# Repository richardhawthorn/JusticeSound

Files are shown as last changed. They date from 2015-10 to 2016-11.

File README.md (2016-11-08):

### Description

Justice Cross

### Features

- 28 LED display
- Charlieplex LED control
- ATTINY44 processor
- 3V operation @ 1Mhz or 8Mhz
- 1x button
- ICSP port
- Hole for necklace chain

### License

This work is licensed under a Creative Commons Attribution-ShareAlike 4.0 International License.

<br />
Designed by <a xmlns:cc="http://creativecommons.org/ns#" href="http://www.richardhawthorn.com" property="cc:attributionName" rel="cc:attributionURL" target="_blank">Richard Hawthorn</a><br />
<a rel="license" href="http://creativecommons.org/licenses/by-sa/4.0/" target="_blank">View License</a>

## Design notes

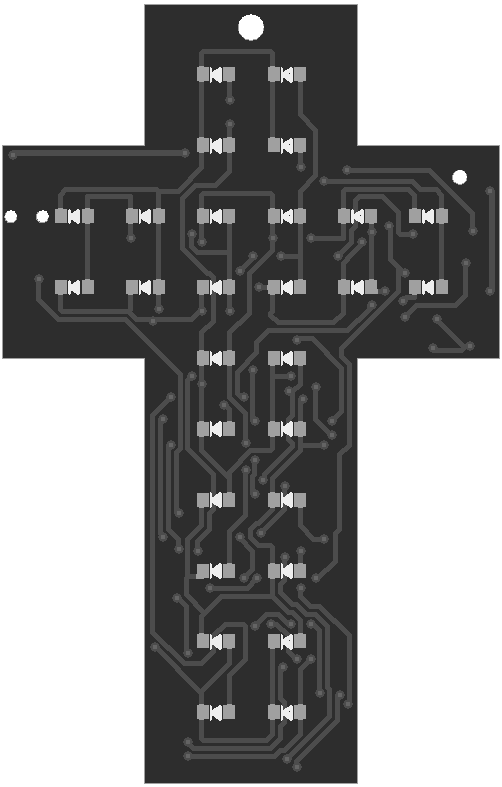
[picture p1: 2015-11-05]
images/pcb_front.png

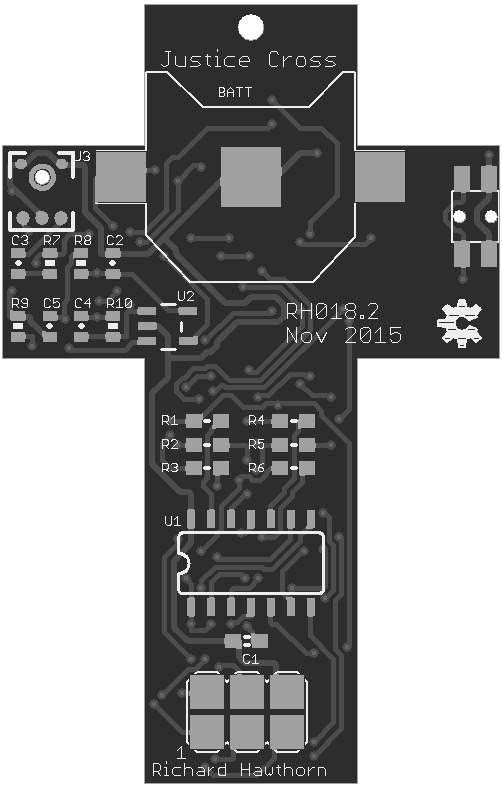
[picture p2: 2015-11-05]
images/pcb_back.png

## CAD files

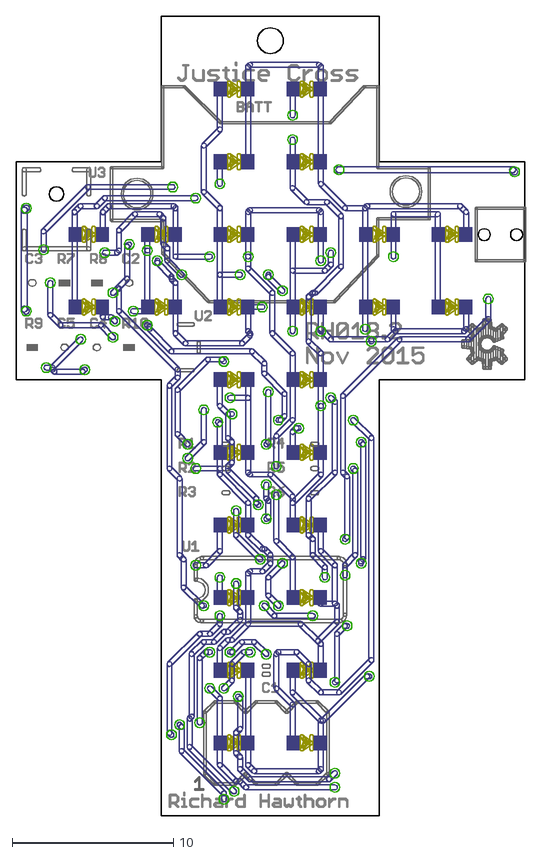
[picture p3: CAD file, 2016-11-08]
enclosure/RH018.2.dxf
31.6 x 49.5

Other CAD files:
enclosure/Enclosure.dxf

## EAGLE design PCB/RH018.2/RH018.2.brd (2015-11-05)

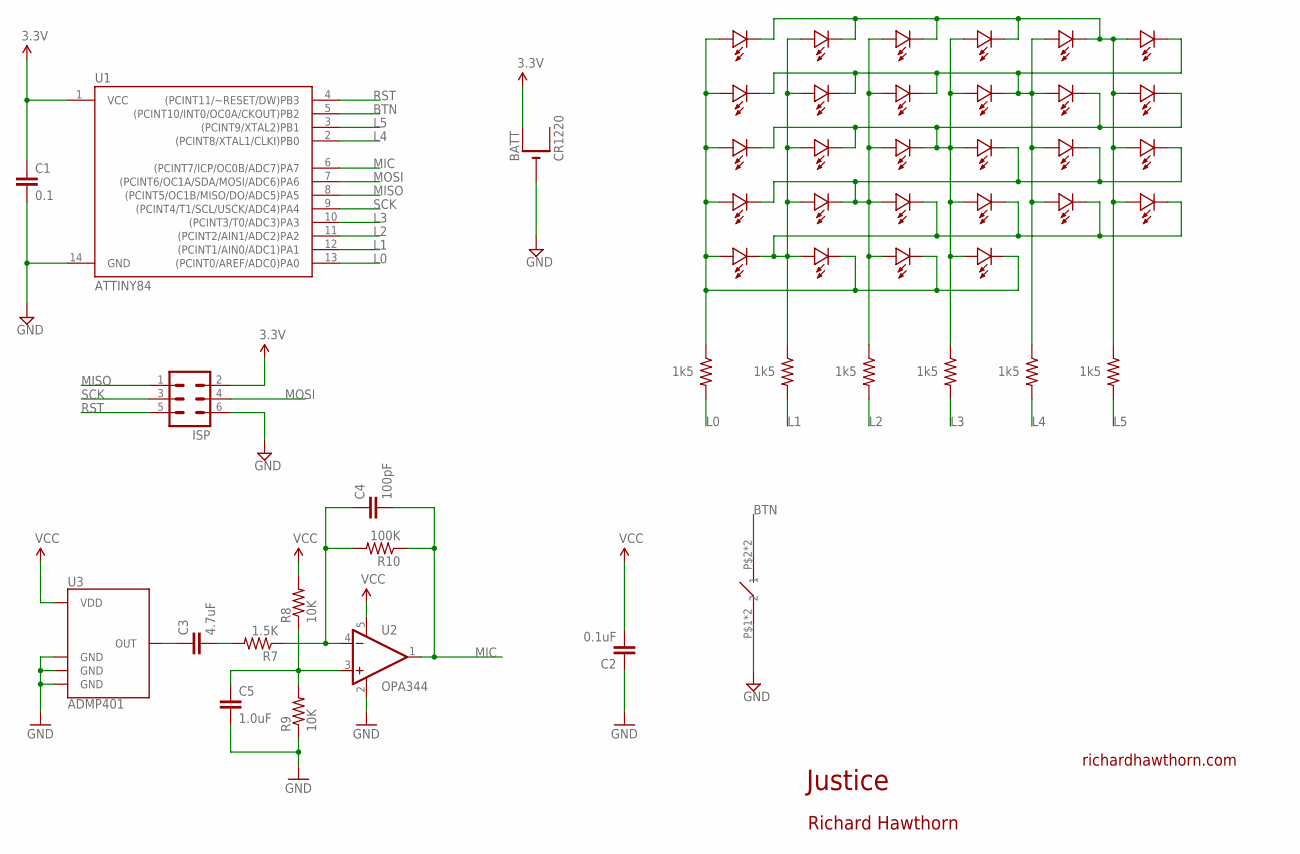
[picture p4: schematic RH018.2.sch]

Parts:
BATT: CR1220; CR1220-SMD
BTN1: TURTLE-3PIN
C1: 0.1; 0603-CAP
C2: 0.1uF; 0402-CAP
C3: 4.7uF; 0402-CAP
C4: 100pF; 0402-CAP
C5: 1.0uF; 0402-CAP
ISP: MA03-2
LED1, LED2, LED3, LED4, LED5, LED6, LED7, LED8, LED9, LED10, LED11, LED12, LED13, LED14, LED15, LED16, LED17, LED18, LED19, LED20, LED21, LED22, LED23, LED24, LED25, LED26, LED27, LED28: LED0603; 0603-LED
R1, R2, R3, R4, R5, R6: 1k5; 0603-RES
R7: 1.5K; 0402-RES
R8, R9: 10K; 0402-RES
R10: 100K; 0402-RES
U1: ATTINY84; SO14
U2: OPA344; SOT23-5
U3: ADMP401

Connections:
BTN: BTN1.P$2 (2), BTN1.P$4 (2), U1.5 ((PCINT10/INT0/OC0A/CKOUT)PB2)
C7N$1: C3.1, U3.1 (OUT)
GND: BATT.-, BTN1.P$1 (1), BTN1.P$3 (1), C1.2, C2.1, C5.2, ISP.6, R9.1, U1.14 (GND), U2.2 (V-), U3.2 (GND), U3.4 (GND), U3.6 (GND)
L0: R1.2, U1.13 ((PCINT0/AREF/ADC0)PA0)
L1: R2.2, U1.12 ((PCINT1/AIN0/ADC1)PA1)
L2: R3.2, U1.11 ((PCINT2/AIN1/ADC2)PA2)
L3: R4.2, U1.10 ((PCINT3/T0/ADC3)PA3)
L4: R5.2, U1.2 ((PCINT8/XTAL1/CLKI)PB0)
L5: R6.2, U1.3 ((PCINT9/XTAL2)PB1)
MIC: C4.2, R10.1, U1.6 ((PCINT7/ICP/OC0B/ADC7)PA7), U2.1 (OUT)
MISO: ISP.1, U1.8 ((PCINT5/OC1B/MISO/DO/ADC5)PA5)
MOSI: ISP.4, U1.7 ((PCINT6/OC1A/SDA/MOSI/ADC6)PA6)
unnamed: C4.1, R7.1, R10.2, U2.4 (-IN)
unnamed: C3.2, R7.2
unnamed: C5.1, R8.1, R9.2, U2.3 (+IN)
unnamed: LED1.MINUS, LED2.MINUS, LED3.MINUS, LED4.MINUS, LED5.MINUS, LED6.PLUS, LED12.PLUS, LED18.PLUS, LED24.PLUS, R6.1
unnamed: LED2.PLUS, LED8.PLUS, LED14.PLUS, LED20.PLUS, LED21.MINUS, LED22.MINUS, LED23.MINUS, LED24.MINUS, LED25.MINUS, LED26.PLUS, R2.1
unnamed: LED1.PLUS, LED7.PLUS, LED13.PLUS, LED19.PLUS, LED25.PLUS, LED26.MINUS, LED27.MINUS, LED28.MINUS, R1.1
unnamed: LED5.PLUS, LED6.MINUS, LED7.MINUS, LED8.MINUS, LED9.MINUS, LED10.MINUS, LED11.PLUS, LED17.PLUS, LED23.PLUS, R5.1
unnamed: LED4.PLUS, LED10.PLUS, LED11.MINUS, LED12.MINUS, LED13.MINUS, LED14.MINUS, LED15.MINUS, LED16.PLUS, LED22.PLUS, LED28.PLUS, R4.1
unnamed: LED3.PLUS, LED9.PLUS, LED15.PLUS, LED16.MINUS, LED17.MINUS, LED18.MINUS, LED19.MINUS, LED20.MINUS, LED21.PLUS, LED27.PLUS, R3.1
RST: ISP.5, U1.4 ((PCINT11/~RESET/DW)PB3)
SCK: ISP.3, U1.9 ((PCINT4/T1/SCL/USCK/ADC4)PA4)
VCC: BATT.+$1 (+), C1.1, C2.2, ISP.2, R8.2, U1.1 (VCC), U2.5 (V+), U3.5 (VDD)

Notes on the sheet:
Justice
richardhawthorn.com
Richard Hawthorn

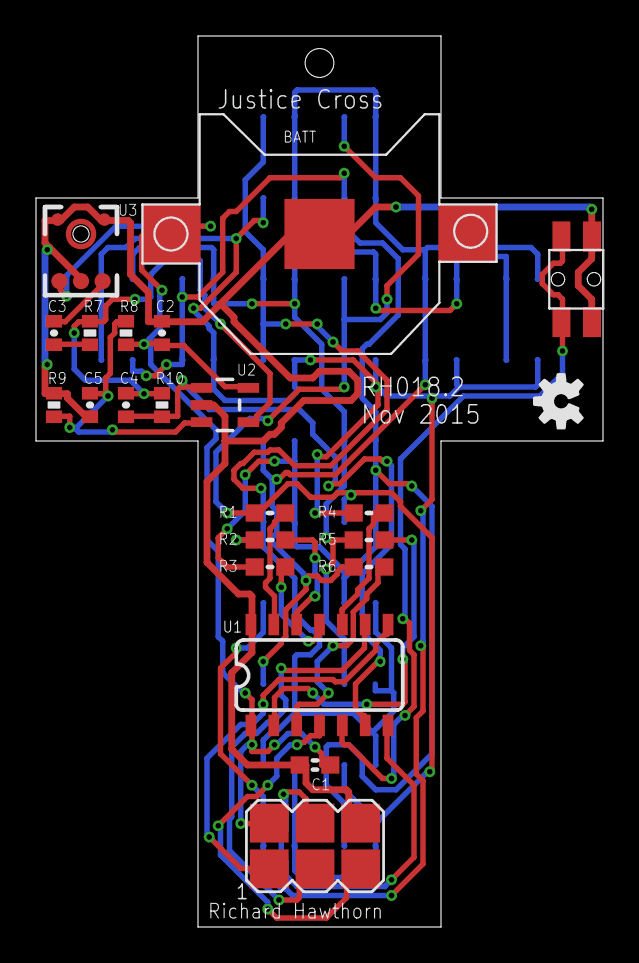
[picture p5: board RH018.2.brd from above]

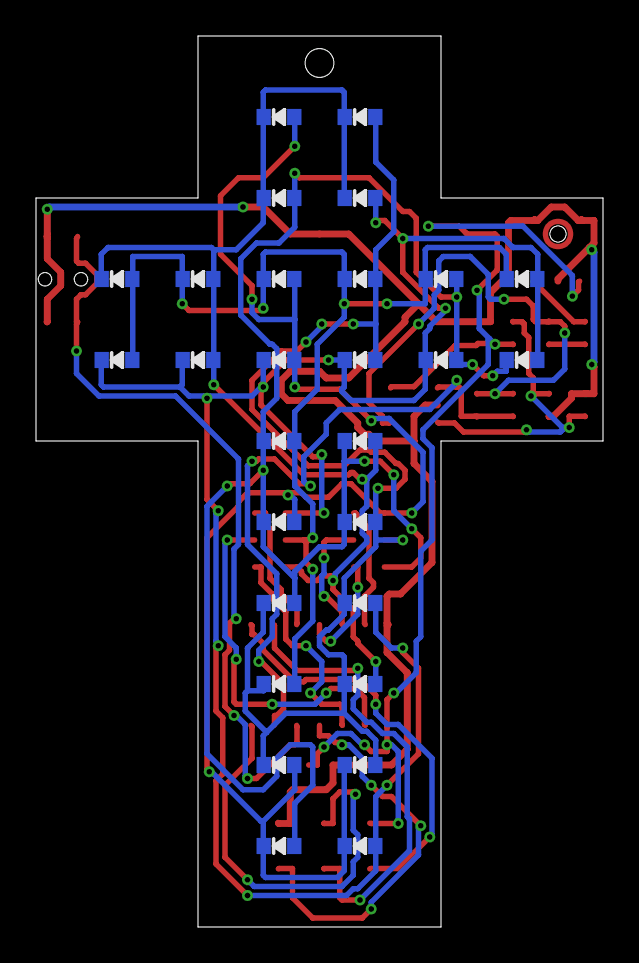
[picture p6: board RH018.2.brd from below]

Board: 2 copper layers, 31.5 x 49.5 mm, 50 parts (28 on the bottom side), 24 nets.

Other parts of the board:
U$3: OSHW-LOGO-S

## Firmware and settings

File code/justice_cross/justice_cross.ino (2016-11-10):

/*
 * Justice Cross
 * Richard Hawthorn
 * richardhawthorn.com
 * 2016-11-09
 */

/*
 * Pin setup
 */
int led_pins[] = {0,1,2,3,10,9};
int btn = 8;

/*
 * Globals
 */
int leds[48];
int menu = 0;
long loopPos = 0;
int led_loop = 0;
int on = 1;
int counts[] = {1, 50, 100};

/*
 * Setup the board
 */
void setup() {

  //delay for 2 seconds before getting started  
  delay(2000);

  //setup the button pin
  pinMode(btn, INPUT_PULLUP);

}


/*
 * Main Loop
 */
void loop() {

  determineLedStatus();
  displayLeds();
  checkButton();

}

/*
 * Check the button
 */
void checkButton(){

  if (!digitalRead(btn)){
    menu++;
    delay(500);
  }
  
}

/*
 * Loop through the menu and determine what our leds should be doing
 */
void determineLedStatus(){

  loopPos++;
   
  if (menu > 3){
    
    menu = 0;
  
  } else if (menu == 0){
    
    on = true;
    
  } else if (menu == 3){

    if (loopPos > 10){
       loopPos = 0;

       for(int p = 0; p <= 47; p++){
          leds[p] = random(0,2);
       }
  
    } 

  } else {

    if (loopPos < (counts[menu] / 2)){
       on = true;
    } else {
       on = false;
    }

    if (loopPos > counts[menu]){
      loopPos = 0;
    }

  }

}

/*
 * Display our pattern on the leds
 */
void displayLeds(){

  led_loop = 0;

  for (int i = 0; i <= 5; i++){
    pinMode(led_pins[i], OUTPUT); 
    digitalWrite(led_pins[i], LOW); 

    for (int j = 0; j <= 5; j++){
      if (i != j){

        if (menu == 3){
          on = leds[led_loop];
        }

        led_loop++;
        
        if (on){
          pinMode(led_pins[j], OUTPUT);
          digitalWrite(led_pins[j], HIGH); 
        }
      }
    }

    delayMicroseconds(600);

    for (int k = 0; k <= 5; k++){
      if (i != k){
          digitalWrite(led_pins[k], LOW); 
          pinMode(led_pins[k], INPUT);
      }
    }
    
    digitalWrite(led_pins[i], HIGH); 
    pinMode(led_pins[i], INPUT); 
    
  }

}

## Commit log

2015-10-01 First version of 1.1
    [JusticeSound1.1.brd, JusticeSound1.1.sch]
2015-10-01 adding v1.2
    [JusticeSound1.2.brd, JusticeSound1.2.sch]
2015-11-05 Rename files
    [JusticeSound1.1.brd, RH018.1.brd, RH018.1.sch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]
2015-11-05 update silk screen
    [RH018.2.brd]
2015-11-05 added back pcb image
2015-11-05 added gerbers
2016-11-08 Adding a laser cut enclosure
    [Enclosure.dxf, RH018.2.dxf]
2016-11-10 add first version of the Arduino code

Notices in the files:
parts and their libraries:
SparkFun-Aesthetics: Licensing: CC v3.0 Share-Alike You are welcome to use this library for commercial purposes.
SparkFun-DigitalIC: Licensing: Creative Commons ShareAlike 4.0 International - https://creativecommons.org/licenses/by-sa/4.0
